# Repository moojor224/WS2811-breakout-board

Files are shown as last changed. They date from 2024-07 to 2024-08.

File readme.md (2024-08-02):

# WS2811 Breakout Board

## v1 (failed design)

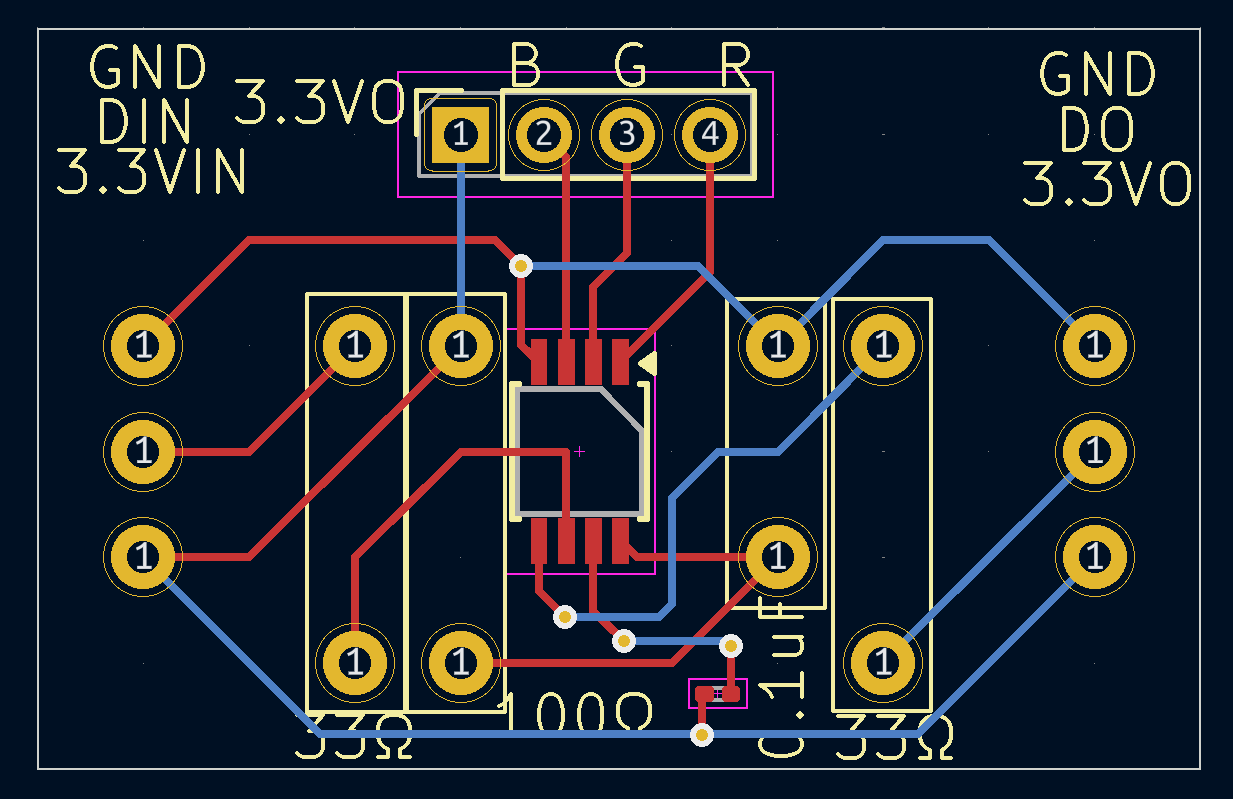
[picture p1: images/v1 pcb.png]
v1 pcb

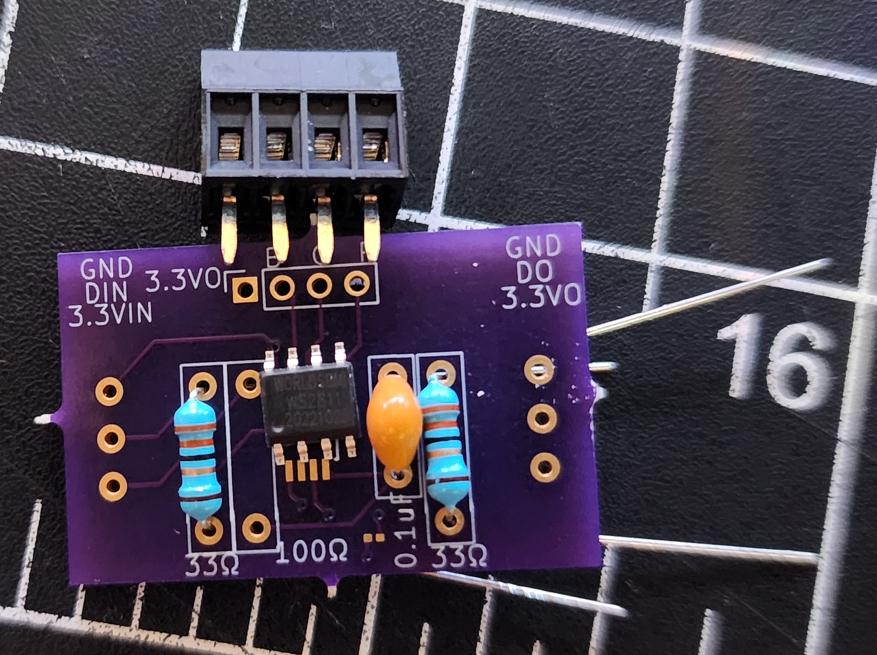
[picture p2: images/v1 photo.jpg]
v1 photo


unfortunately, I decided that I was too good at making pcbs to take any measurements before ordering the boards, so I found the following issues after they arrived:

 - the 4 pin header at the top of the board had the wrong spacing (too close together)
 - the sop-8 footprint was the wrong size (too small)
 - the through-holes for the terminal blocks were too small for the terminal block pins
 - the smd resistor pads for low-speed enable are too small to realisically solder
 - the100 ohm resistor from 3.3VIN to VDD was not necessary and could be removed to save space

## v2

This time around, I actually measured the components I had and adjusted the incorrect components like so.
 - replace the 4-pin footprint with 4 individual through-holes
 - increase the inner diameter of all terminal block through holes to 1mm
 - double the width of all traces

Additionally, the board shrunk by 0.1 inches horizontally due to taking out the 100 ohm resistor

while checking if I soldered the IC to the pcb correctly, I found that the in/out GND pins at the left/right side of the pcb were not connected. This is temporarily fixable by simply connecting the screw terminals with a short length of wire, but is fixed in V2.5

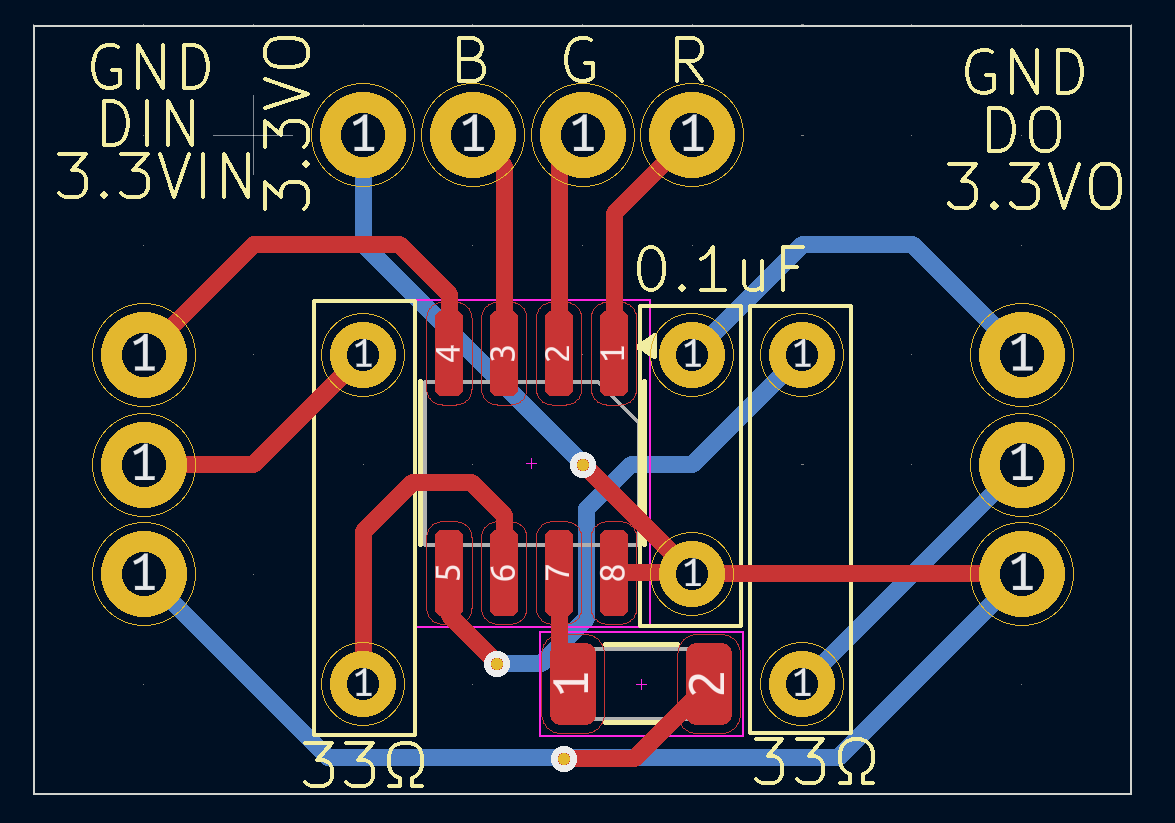
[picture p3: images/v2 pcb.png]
v2 pcb

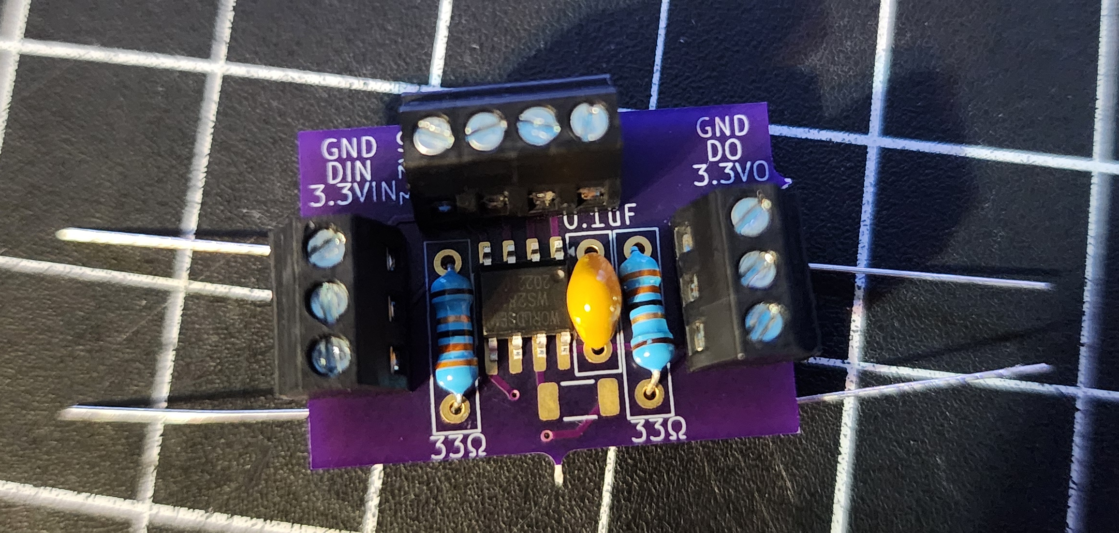
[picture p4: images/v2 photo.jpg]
v2 photo


## v2.5

this version is just a re-route of v2 to put the traces on one side
also fixes the gnd disconnect mistake from V2

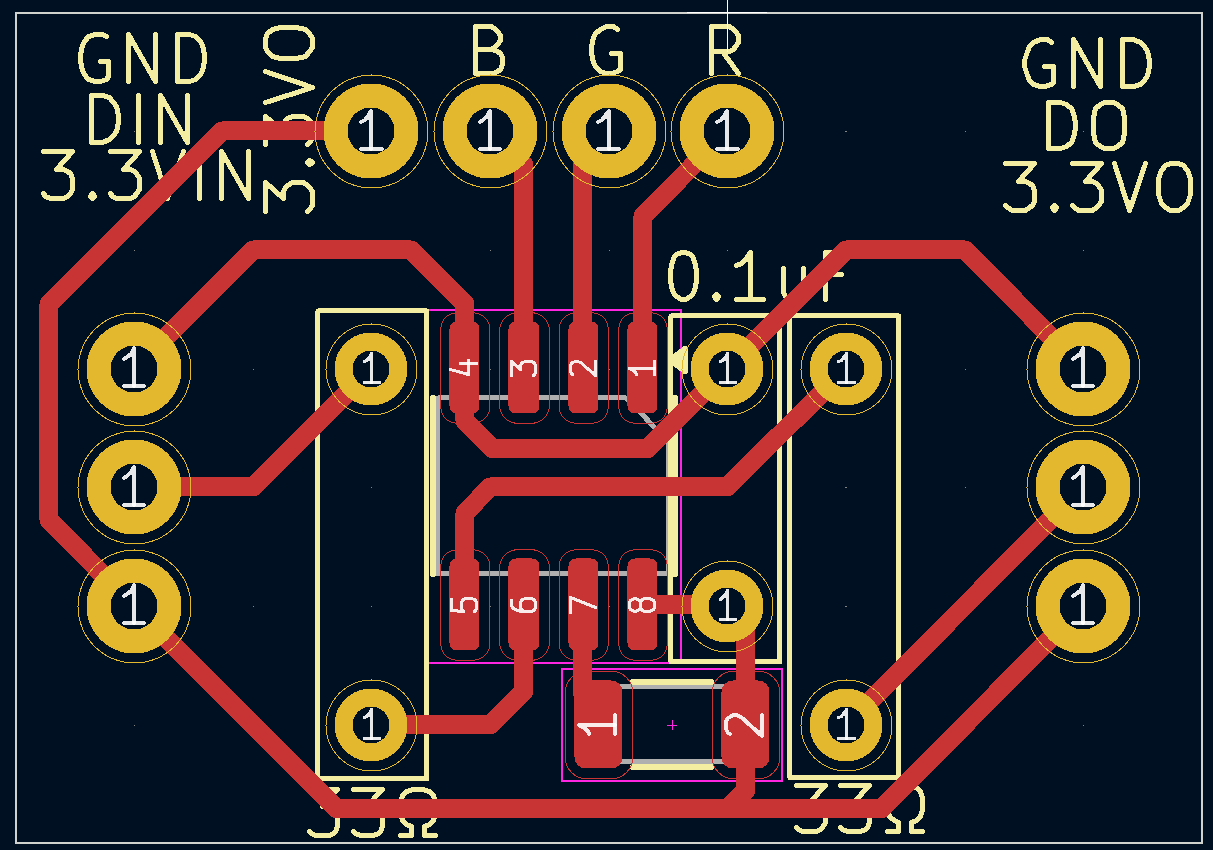
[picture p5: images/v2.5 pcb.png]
v2.5 pcb

v2.5 photo pending

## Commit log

2024-07-12 update fabrication files
    [WS2811 breakout board-B_Cu.gbr, WS2811 breakout board-B_Mask.gbr, WS2811 breakout board-B_Paste.gbr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]
2024-07-23 fix sizing issues
    [WS2811 breakout board.kicad_pcb]
2024-07-23 export latest gerber files
    [WS2811 breakout board-B_Cu.gbr, WS2811 breakout board-B_Mask.gbr, WS2811 breakout board-B_Paste.gbr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]
2024-07-23 fix missing trace
    [WS2811 breakout board.kicad_pcb]
2024-07-23 fix another missing trace
    [WS2811 breakout board.kicad_pcb]
2024-07-26 update board to v2.5
    [WS2811 breakout board.kicad_pcb]
2024-08-02 fix gnd trace disconnect
    [WS2811 breakout board.kicad_pcb]
2024-11-04 add compact smd versions of the board
    [WS2811 breakout board smd castellated.kicad_pcb, WS2811 breakout board smd.kicad_pcb, WS2811 breakout board.kicad_pcb]
